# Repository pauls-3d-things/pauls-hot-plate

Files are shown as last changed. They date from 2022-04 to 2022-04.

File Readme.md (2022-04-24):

# SMD Soldering Station / Hotplate

**WARNING! If you have no experience wiring mains, do not proceed with this project. USE THIS INFORMATION YOUR OWN RISK!!**

## Support my projects ❤️

It takes me countless hours to prepare and document my projects. [You can support me by reading/recommending my books.](https://p3dt.net/books.html) Thank you!

## License

See `License` file. GPLv3.

## Introduction

This is a project to build a DIY PID controlled hotplate. This includes a python script to create a temperature chart and a tiny PCB to extend a TTGO 1.3" OLED shield as a controller.

- ESP8266 OLED board: https://www.aliexpress.com/item/32854542718.html
- SMD Hot plate, maybe something like this: https://www.aliexpress.com/item/1005003120565125.html
- SSR-25 DA Solid State Module
- Hot plate adapter board: see `hardware/` for KiCAD sources, or order here: https://aisler.net/p/AJJEAEVL
- 1x4.7k, 1x10k 0603 resitor
- 1x100k Thermistor (from my 3D printer)
- 2x8pin female header
- 3x2pin JST-XH 2.50mm
- Code: see `firmware/`

## firmware

Open the folder `firmware/` with Visual Studio Code and install recommended plugins. You can find VSC here: https://code.visualstudio.com

The trickiest part was to get the temperature readings correct.
I had the best results using the *Stein-Hart* model to obtain correct temperature readings (which only works above 40C, but as we want to solder somethings, this should be OK ;) ). If you are using a different setup, you will need to adapt the line in `main.cpp`, using values derived with this tool: https://www.thinksrs.com/downloads/programs/therm%20calc/ntccalibrator/ntccalculator.html

```c++
SteinhartHart sh(SENSOR_PIN, 4700, 1.719817401e-3, 0.3527370551e-4, 10.70472184e-7);
```

The software has two modes: constant temperature and reflow. You can adapt the reflow curve by changing the setup code. The constructor takes the *label of the phase*, *the temperature in C*, *how long to hold the temperature in millis*, and *the kP* factor (higher value = more agressive heating = overshooting). I've set the *kP* high to quickly reach the max temp at end of the reflow phase:

```c++
void setupTempControl() {
  tempControl.add(new TempStep("heatup", HEATUP, 120, 1 * 1000, 1.0));
  tempControl.add(new TempStep("soak", HEATUP, 150, 80 * 1000, 1.5));
  tempControl.add(new TempStep("reflow", HEATUP, 230, 1 * 1000, 3.0));
  tempControl.add(new TempStep("reflow", HEATUP, 245, 3 * 1000, 10.0));
  tempControl.add(new TempStep("cooldown", COOLDOWN, 50, 10 * 1000));
}
```

## hardware

The overall setup *could* look like this, the setup below is only for educational purposes:

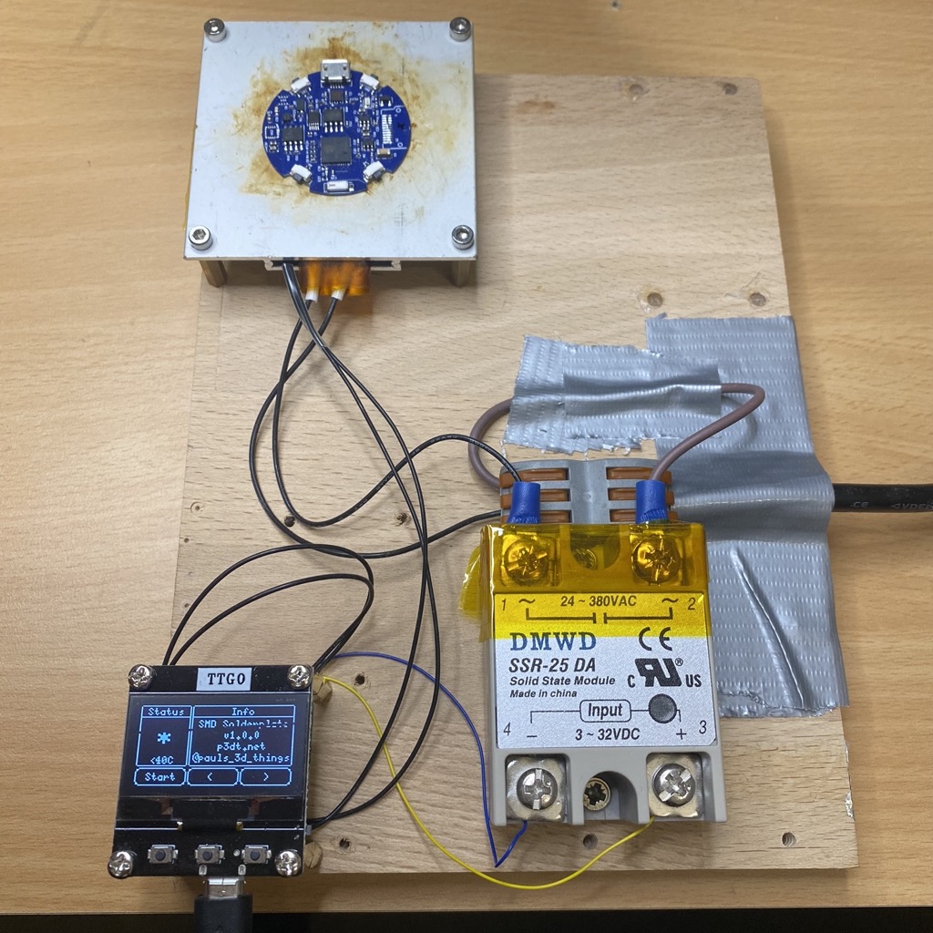
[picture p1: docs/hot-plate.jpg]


**DO NOT LEAVE THE MAINS VOLTAGE TERMINALS EXPOSED!!**

I used the following adapter to connect everything to the EPS8266 board:

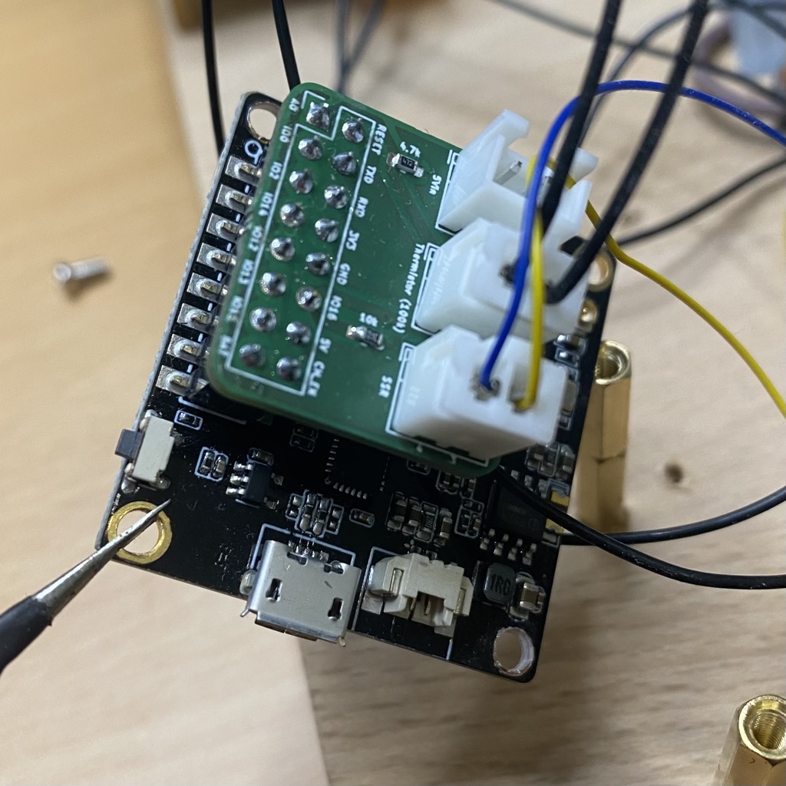
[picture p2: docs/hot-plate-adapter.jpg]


The schematics:

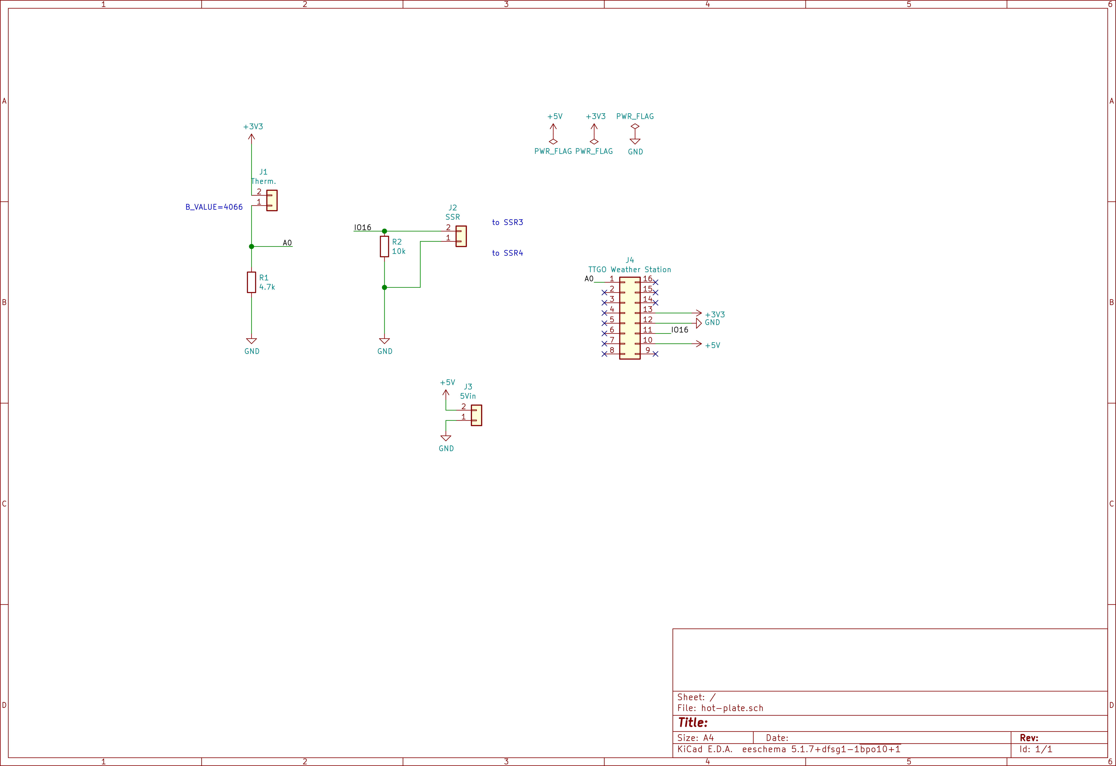
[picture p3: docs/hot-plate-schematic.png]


## serial-plotter

Requires Python

```bash
pip3 install matplotlib
pip3 install pyserial
```

Usage:

```bash
python3 main.py /dev/cu.usb... 115200
```

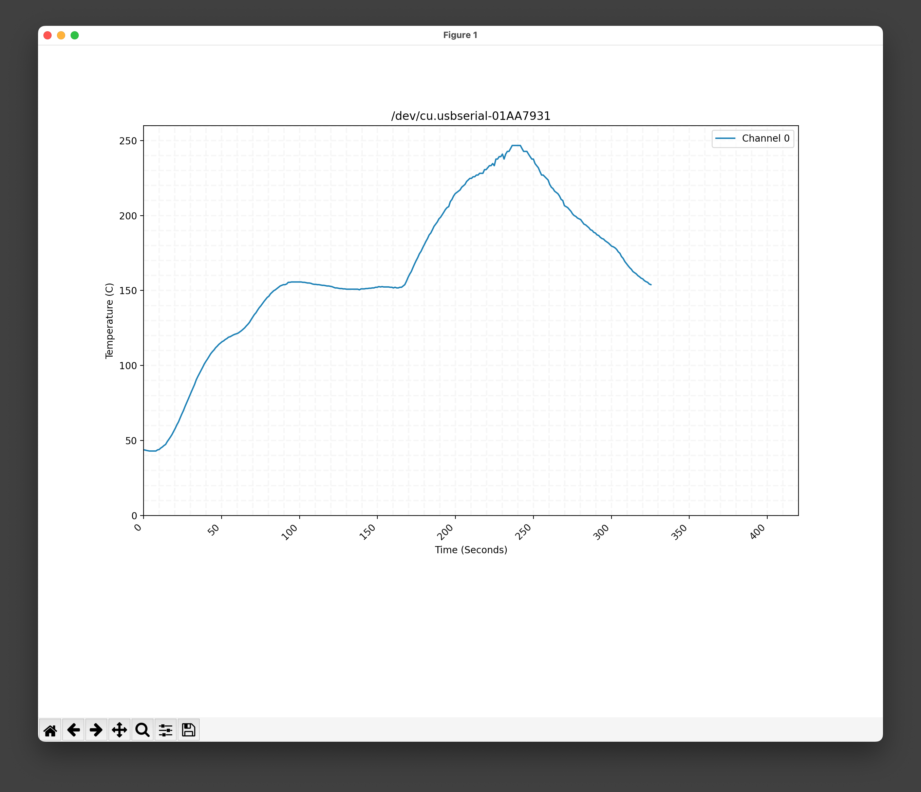
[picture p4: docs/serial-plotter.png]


### On Error: can't import serial

If the `import serial` fails

```bash
pip3 uninstall serial
pip3 uninstall pyserial

pip3 install pyserial
```

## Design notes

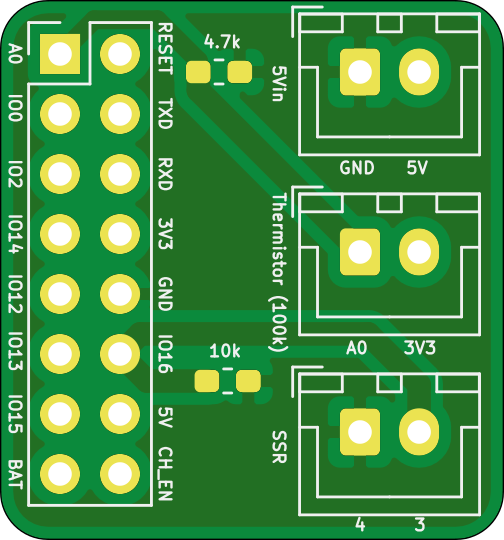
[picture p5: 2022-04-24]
docs/hot-plate-bottom.png

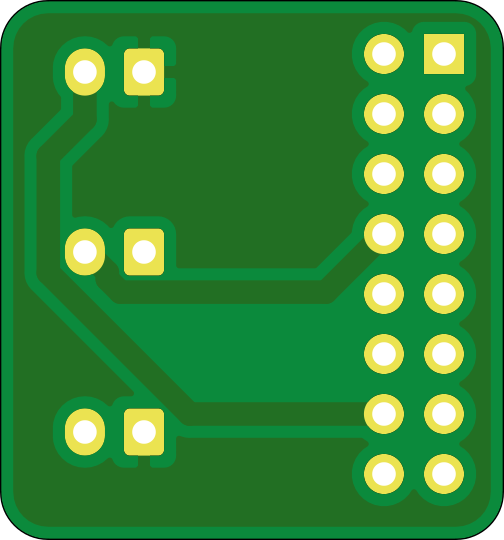
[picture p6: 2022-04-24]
docs/hot-plate-top.png

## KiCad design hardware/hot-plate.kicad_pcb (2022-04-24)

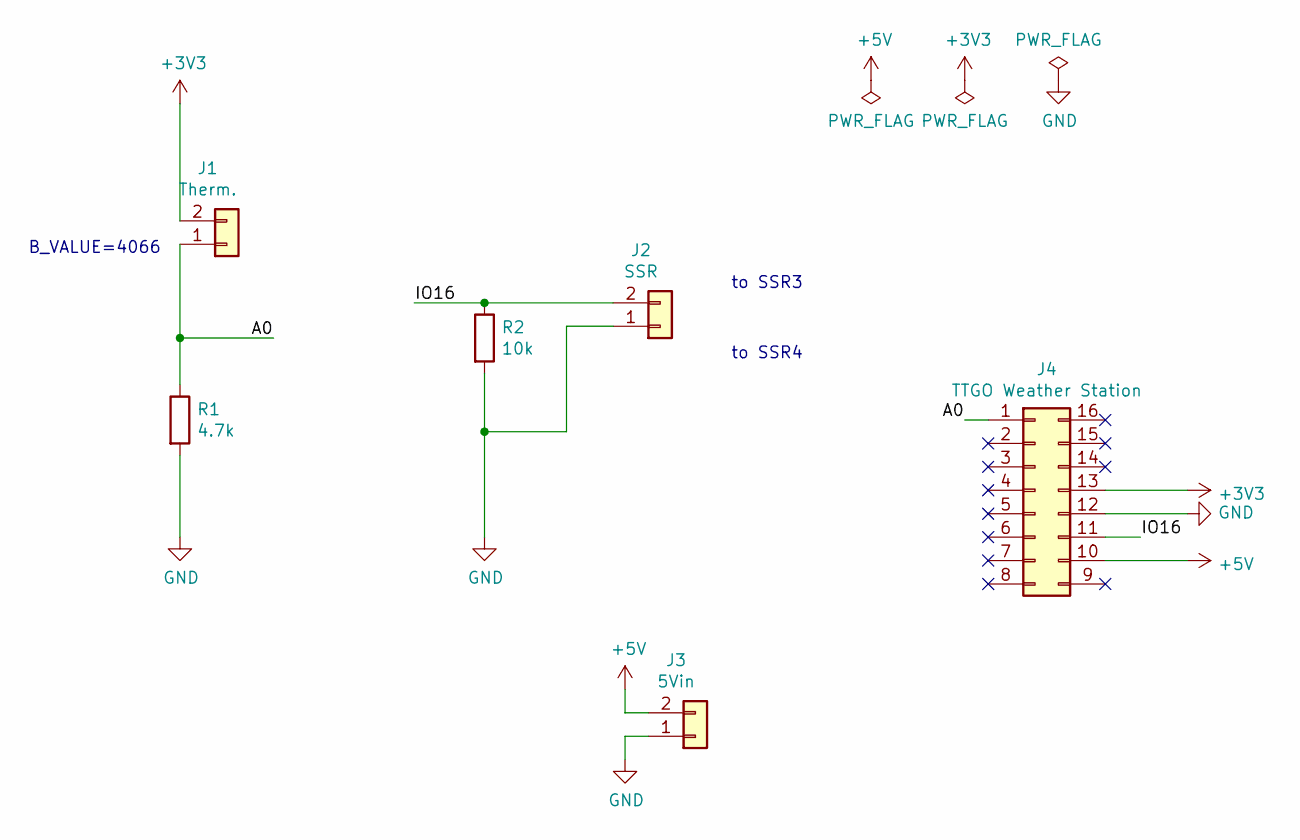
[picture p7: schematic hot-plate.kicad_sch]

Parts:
J1: Therm.; JST_XH_B2B-XH-A_1x02_P2.50mm_Vertical
J2: SSR; JST_XH_B2B-XH-A_1x02_P2.50mm_Vertical
J3: 5Vin; JST_XH_B2B-XH-A_1x02_P2.50mm_Vertical
J4: TTGO Weather Station; PinHeader_2x08_P2.54mm_Vertical
R1: 4.7k; R_0603_1608Metric_Pad1.05x0.95mm_HandSolder
R2: 10k; R_0603_1608Metric_Pad1.05x0.95mm_HandSolder

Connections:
+3V3: J1.2, J4.13
+5V: J3.2, J4.10
/A0: J1.1, J4.1, R1.1
/IO16: J2.2, J4.11, R2.1
GND: J2.1, J3.1, J4.12, R1.2, R2.2

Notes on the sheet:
B_VALUE=4066
to SSR3
to SSR4

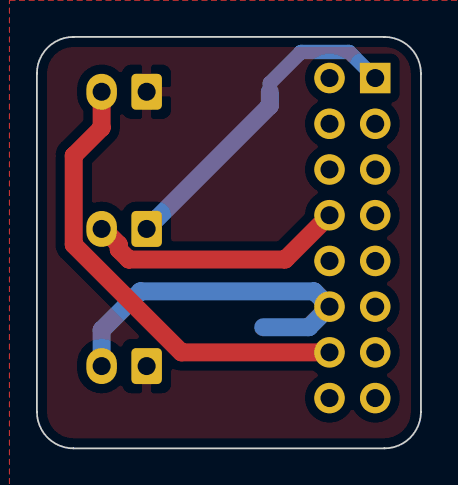
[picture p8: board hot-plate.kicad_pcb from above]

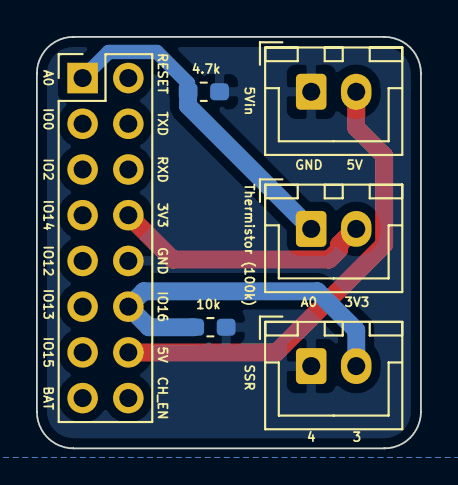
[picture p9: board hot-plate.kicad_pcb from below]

Board: 2 copper layers, 21.3 x 22.9 mm, 6 parts (6 on the bottom side), 5 nets.

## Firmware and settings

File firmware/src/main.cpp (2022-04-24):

#include <Arduino.h>
#include <PID_v1.h>
#include <SteinhartHart.h>
#include <U8g2lib.h>
#include <Wire.h>

#include "config.h"
#include "temp_control.h"
#include "ui.h"

// the magic values below are acquired via
// https://www.thinksrs.com/downloads/programs/therm%20calc/ntccalibrator/ntccalculator.html
// measure with an external thermometer and print out the measured resistance
// inside sh.getTempKelvin(...) with Serial.println(resistance);
SteinhartHart sh(SENSOR_PIN, 4700, 1.719817401e-3, 0.3527370551e-4, 10.70472184e-7);
TempControl tempControl;

float temp = 0;

#define NUM_STATES 2
enum MODE_STATE { SELECT = 0, RUNNING = 1 };
#define NUM_MODES 3
enum MODE { INFO = 0, SMD = 1, CUSTOM_TEMP = 2 };

MODE_STATE modeState = SELECT;
MODE mode = INFO;
String modeTitle = "ready";
uint16_t modeDuration = 0;
uint8_t modeProgress = 0;

#define HISTORY_LEN 83
#define HISTORY_INTERVALL 2000
uint8_t history[HISTORY_LEN];
uint8_t historyPtr = 0;
long lastHistoryUpdate = 0;

U8G2_SH1106_128X64_NONAME_F_HW_I2C u8g2(U8G2_R0, /* reset=*/U8X8_PIN_NONE);

// variables for output control
long heatingSince = 0;
long coolingSince = 0;
long lastChange = 0;
long runningSince = 0;

#define TEMP_WINDOW 2000  // two seconds
#define SWITCH_SPEED 25   // dont switch faster than this

// variables for PID
double targetTemp, pidInput, pidOutput;
double Kp = 1, Ki = 0.01, Kd = 0.5;
PID myPID(&pidInput, &pidOutput, &targetTemp, Kp, Ki, Kd, DIRECT);

void setupButtons() {
  pinMode(BTN_LEFT, INPUT_PULLUP);
  pinMode(BTN_MID, INPUT_PULLUP);
  pinMode(BTN_RIGHT, INPUT_PULLUP);
}

void setupSSR() {
  pinMode(PIN_SSR, OUTPUT);
  coolingSince = millis();
  targetTemp = CUSTOM_TEMP_START;

  // turn the PID on
  myPID.SetMode(AUTOMATIC);
}

void resetHistory() {
  for (uint8_t x = 0; x < HISTORY_LEN; x++) {
    history[x] = 0;
  }
}

void setupTempControl() {
  tempControl.add(new TempStep("heatup", HEATUP, 120, 1 * 1000, 1.0));
  tempControl.add(new TempStep("soak", HEATUP, 150, 80 * 1000, 1.5));
  tempControl.add(new TempStep("reflow", HEATUP, 230, 1 * 1000, 3.0));
  tempControl.add(new TempStep("reflow", HEATUP, 245, 3 * 1000, 10.0));
  tempControl.add(new TempStep("cooldown", COOLDOWN, 50, 10 * 1000));
}

void setup(void) {
  Serial.begin(115200);
  Wire.begin(5, 4);  // (CLK,SDA)
  u8g2.begin();
  setupButtons();

  setupSSR();
  resetHistory();
  setupTempControl();
}

void applyOutput() {
  long now = millis();
  if (now - lastChange < SWITCH_SPEED) {
    // do not switch faster than SWITCH_SPEED
    return;
  }

  // approach: never heat longer than
  // window * (Output/maxOutput)
  // => 255 => always on
  // => 0 => always off

  if (heatingSince > coolingSince && pidOutput < 255) {  // TODO: remove the < ?
    // we are (partially) heating

    if (now - heatingSince > TEMP_WINDOW * (pidOutput / 255.0)) {
      // turn off
      digitalWrite(PIN_SSR, LOW);
      coolingSince = now;
      lastChange = now;
    }
  } else if (pidOutput > 4) {  // magic value to limit overshooting a bit
    // we are (partially) cooling
    if (now - coolingSince > TEMP_WINDOW * ((255 - pidOutput) / 255.0)) {
      // turn on
      digitalWrite(PIN_SSR, HIGH);
      heatingSince = now;
      lastChange = now;
    }
  }
}

void drawUI(U8G2 u8g2) {
  static long counter = 0;
  counter++;

  // left: status
  u8g2.setDrawColor(1);
  u8g2.setFont(u8g2_font_5x8_tf);
  button(u8g2, 0, 50, 42, modeState == RUNNING ? "Stop" : "Start", modeState == RUNNING);
  dialog(u8g2, 0, 0, 42, 49, String("Status"));
  if (temp >= 40) {
    u8g2.setDrawColor(1);
    u8g2.drawTriangle(6, 38, 21, 13, 35, 38);

    u8g2.setDrawColor((counter + 1) % 2);
    u8g2.drawTriangle(9, 36, 21, 16, 32, 36);

    u8g2.setDrawColor(counter % 2);
    u8g2.setFont(u8g2_font_profont22_tf);
    u8g2.drawStr(16, 35, "!");

    u8g2.setDrawColor(1);
    u8g2.setFont(u8g2_font_profont10_tf);
    u8g2.drawStr(11, 47, (String(temp, 0) + "C").c_str());
  } else {
    u8g2.setFont(u8g2_font_profont22_tf);
    u8g2.drawStr(16, 35, "*");

    u8g2.setFont(u8g2_font_profont10_tf);
    u8g2.setDrawColor(1);
    u8g2.drawStr(11, 47, "<40C");
  }

  // right: mode
  u8g2.setFont(u8g2_font_5x8_tf);
  if (modeState != RUNNING || mode == CUSTOM_TEMP) {
    button(u8g2, 43, 50, 42, "< ", false);
    button(u8g2, 86, 50, 42, ">", false);
  }

  // int analogValue = analogRead(SENSOR_PIN);
  switch (mode) {
    case INFO:
      dialog(u8g2, 43, 0, 85, 49, String("Info"));
      u8g2.drawStr(49, 18, "SMD Solderplate");
      u8g2.drawStr(70, 27, "v1.0.0");
      // u8g2.drawStr(70, 27, String(analogRead(SENSOR_PIN)).c_str());
      u8g2.drawStr(66, 36, "p3dt.net");
      // u8g2.drawStr(66, 36, String(analogValue / 1024.0).c_str());
      u8g2.drawStr(46, 45, "@pauls_3d_things");
      break;
    case CUSTOM_TEMP:
      dialog(u8g2, 43, 0, 85, 49, String("Custom Temp."));
      u8g2.setFont(u8g2_font_profont22_tf);
      u8g2.drawStr(64, 35, (String(targetTemp, 0) + "C").c_str());
      break;
    case SMD:
      dialog(u8g2, 43, 0, 85, 49, String(modeState == SELECT ? "SMD Soldering" : modeTitle));

      u8g2.drawStr(46, 18, (String(targetTemp, 0) + "C").c_str());
      u8g2.drawStr(100, 18,
                   (String(modeDuration / 1000) + "s "  //
                    + (tempControl.isStepReached() ? "" : (tempControl.isHeating() ? "^" : "v")))
                       .c_str());
      if (modeState == RUNNING) {
        progressBar(u8g2, 43, 50, 85, 14, modeProgress);
      }
      u8g2.drawFrame(44, 20, 83, 28);

      // draw history
      for (uint8_t x = 0; x < HISTORY_LEN; x++) {
        uint8_t y = history[(historyPtr + x) % HISTORY_LEN];
        u8g2.drawVLine(44 + x, 47 - y, y);
      }
      break;
  }
}

void loop(void) {
  // temp = thermistor->readCelsius();
  temp = sh.getTempCelsius();
  static long lastPrint = 0;
  // rate limit serial output
  if (lastPrint < millis() - 1000) {
    Serial.println(temp);
    lastPrint = millis();
  }

  if (modeState == RUNNING) {
    pidInput = temp;
    myPID.Compute();
    applyOutput();

    switch (mode) {
      case INFO:
      case CUSTOM_TEMP:
        // nothing to do here!
        break;
      case SMD:
        if (millis() - lastHistoryUpdate > HISTORY_INTERVALL) {
          // assume max temp is 280 -> 28 pixels = 1px = 28C
          history[historyPtr] = temp > 40 ? (temp - 40) / 10 : 0;
          historyPtr = (historyPtr + 1) % HISTORY_LEN;
          lastHistoryUpdate = millis();
        }

        tempControl.update(temp);
        targetTemp = tempControl.getTargetTemp();
        modeTitle = tempControl.getLabel();
        modeDuration = tempControl.getDuration();
        myPID.SetTunings(tempControl.getKp(), myPID.GetKi(), myPID.GetKd());
        if (!tempControl.isRunning()) {
          modeState = SELECT;
        }
        // modeProgress = (elapsed / (1.0 * WARMUP_TIME + PREHEAT_TIME + SOAK_TIME + REFLOW_TIME + COOLDOWN_TIME)) *
        // 100;
        modeProgress = tempControl.getProgress();
        break;
    }
  } else {
    digitalWrite(PIN_SSR, LOW);
  }

  u8g2.clearBuffer();
  u8g2.setFont(u8g2_font_ncenB08_tr);
  drawUI(u8g2);
  u8g2.sendBuffer();

  // LOW = button down
  if (digitalRead(BTN_LEFT) == LOW) {
    switch (modeState) {
      case SELECT:
        modeState = RUNNING;
        runningSince = millis();
        if (mode == SMD) {
          tempControl.start();
        }
        break;
      case RUNNING:
        modeState = SELECT;
        if (mode == SMD) {
          resetHistory();
          tempControl.stop();
        }
        break;
    }
    delay(500);
  }
  if (digitalRead(BTN_MID) == LOW) {
    if (modeState == SELECT) {
      mode = (MODE)(mode == 0 ? NUM_MODES - 1 : mode - 1);
    } else if (mode == CUSTOM_TEMP) {
      targetTemp -= 10;
    }
    delay(100);
  }
  if (digitalRead(BTN_RIGHT) == LOW) {
    if (modeState == SELECT) {
      mode = (MODE)((mode + 1) % NUM_MODES);
    } else if (mode == CUSTOM_TEMP) {
      targetTemp += 10;
    }
    delay(100);
  }

  delay(50);
}

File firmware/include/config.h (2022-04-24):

#ifndef CONFIG_H
#define CONFIG_H

// hardware pins for TTGO "weather station"
#define BTN_LEFT 12
#define BTN_MID 14
#define BTN_RIGHT 13

#define PIN_SSR 16

#define SENSOR_PIN A0

// reflow timings, first value is how long it takes to reach, second how long should stay

#define CUSTOM_TEMP_START 180
#define WARMUP_TEMP 80
#define WARMUP_TIME 40
#define PREHEAT_TEMP 150
#define PREHEAT_TIME 40 + 60
#define SOAK_TEMP 180
#define SOAK_TIME 30 + 30
#define REFLOW_TEMP 240
#define REFLOW_TIME 60 + 60
#define COOLDOWN_TEMP 0
#define COOLDOWN_TIME 10

#endif

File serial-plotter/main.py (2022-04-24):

import matplotlib.pyplot as plt
import matplotlib.animation as animation
import serial
import time
import sys

# The following blog post helped me write this:
# http://www.mikeburdis.com/wp/notes/plotting-serial-port-data-using-python-and-matplotlib/

if len(sys.argv) < 3:
    print("Usage: python main.py <path-to-serial> <baud-rate>")
    exit(1)

# open serial interface
ser = serial.Serial()
ser.port = sys.argv[1]
ser.baudrate = int(sys.argv[2])
ser.timeout = 10
ser.open()
if ser.is_open == True:
    print("\nAll right, serial port now open. Configuration:\n")
    print(ser, "\n")
else:
    exit(2)

# create figure
fig = plt.figure()
ax = fig.add_subplot(1, 1, 1)
xs = []
ys = []
startTime = time.time()


def update(frame, xs, ys):

    line = ser.readline()
    line_as_list = line.split(b',')
    i = float(line_as_list[0])
    t = time.time() - startTime
    print(t, i)
    xs.append(t)
    ys.append(i)

    # Limit x and y lists to 20 items
    #xs = xs[-20:]
    #ys = ys[-20:]

    ax.clear()

    # Add horizontal
    for yc in range(0, 300, 10):
        plt.axhline(y=yc, color='whitesmoke', linestyle='--')
    for xc in range(0, 440, 10):
        plt.axvline(x=xc, color='whitesmoke', linestyle='--')
    ax.plot(xs, ys, label="Channel 0")

    # Format plot
    plt.xticks(rotation=45, ha='right')
    plt.subplots_adjust(bottom=0.30)
    plt.title(ser.port)
    plt.ylabel('Temperature (C)')
    plt.xlabel('Time (Seconds)')
    plt.legend()
    plt.axis([0, 420, 0, 260])


ani = animation.FuncAnimation(fig, update, fargs=(xs, ys), interval=500)

plt.show()

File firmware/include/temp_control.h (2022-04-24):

#ifndef TEMP_CONTROL_H
#define TEMP_CONTROL_H

#include <Arduino.h>

#include <vector>

#define HEATUP true
#define COOLDOWN false

class TempStep {
 public:
  TempStep(const char* label, bool heatup, double targetTemp, long duration, double kP = 1.0)
      : duration(duration), heatup(heatup), targetTemp(targetTemp), label(label), kP(kP) {
    reachedMillis = 0;
  }
  long duration;
  double targetTemp;
  const char* label;
  bool heatup;
  long reachedMillis;
  double kP;
};

class TempControl {
 public:
  TempControl() {}
  void add(TempStep* step) { this->steps.push_back(step); }

  void start() {
    stepIndex = 0;
    running = true;
    for (int i = 0; i < steps.size(); i++) {
      steps[i]->reachedMillis = 0;
    }
  }
  void stop() { running = false; }

  double getProgress() {
    if (!running || stepIndex >= steps.size()) {
      return 100;
    }
    double totalMillis = 0;
    for (int i = 0; i < steps.size(); i++) {
      totalMillis += steps[i]->duration;
    }

    double elapsedMillis = 0;
    for (int i = 0; i < stepIndex; i++) {
      elapsedMillis += steps[i]->duration;
    }
    // current step progress (0 if not reached)
    long stepElapsed = steps[stepIndex]->reachedMillis ? millis() - steps[stepIndex]->reachedMillis : 0;
    // catch overrun
    stepElapsed = stepElapsed > steps[stepIndex]->duration ? steps[stepIndex]->duration : stepElapsed;
    elapsedMillis += stepElapsed;

    return (elapsedMillis / totalMillis) * 100;
  }

  bool isRunning() { return running; }
  double getKp() {
    if (!running || stepIndex >= steps.size()) {
      return 1.0;
    }
    return steps[stepIndex]->kP;
  }
  double getTargetTemp() {
    if (!running || stepIndex >= steps.size()) {
      return 0.0;
    }
    return steps[stepIndex]->targetTemp;
  }
  long getDuration() {
    if (!running || stepIndex >= steps.size()) {
      return 0;
    }
    return steps[stepIndex]->duration;
  }
  const char* getLabel() {
    if (!running || stepIndex >= steps.size()) {
      return "finished";
    }
    return steps[stepIndex]->label;
  }
  bool isStepReached() {
    if (!running || stepIndex >= steps.size()) {
      return true;
    }
    return steps[stepIndex]->reachedMillis;
  }
  bool isHeating() {
    if (!running || stepIndex >= steps.size()) {
      return true;
    }
    return steps[stepIndex]->heatup;
  }

  void update(double temperature) {
    if (!running || stepIndex >= steps.size()) {
      return;
    }

    TempStep* cs = steps[stepIndex];
    if (!cs->reachedMillis                                         // step not reached yet -> check temp
        && ((cs->heatup && cs->targetTemp <= temperature)          // temperature hot enough
            || (!cs->heatup && temperature <= cs->targetTemp))) {  // temperature cold enough
      cs->reachedMillis = millis();
    } else if (cs->reachedMillis && cs->reachedMillis + cs->duration <= millis()) {  // step reached -> check duration
      stepIndex++;
      if (stepIndex >= steps.size()) {
        running = false;
      }
    }
  }

 private:
  std::vector<TempStep*> steps;
  int stepIndex = 0;
  bool running = false;
};

#endif
